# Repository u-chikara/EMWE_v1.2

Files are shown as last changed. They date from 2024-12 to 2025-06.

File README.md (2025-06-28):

# EMWE_v1.2

2024年度NHK高専ロボコンに出場したロボット「ひまり」と「ほしかご」に搭載していたメインマイコンボードの設計図です。

メインプロセッサ：ATSAME54N19A
統合開発環境：MPLAB

主な機能

CAN-FD 2チャンネル

SERCOM 5チャンネル（そのうち2チャンネルはコントローラと液晶用）

一応９軸IMUも付けられる

100M Ethernet

USB OTG （Type-CとTypeAをスイッチで切り替え）

SD/MMCカードスロット　マイコンに専用の回路があるのでそれで通信する

LEDとタクトスイッチをそれぞれ３つ搭載

今後のロボコンにお役立てください。

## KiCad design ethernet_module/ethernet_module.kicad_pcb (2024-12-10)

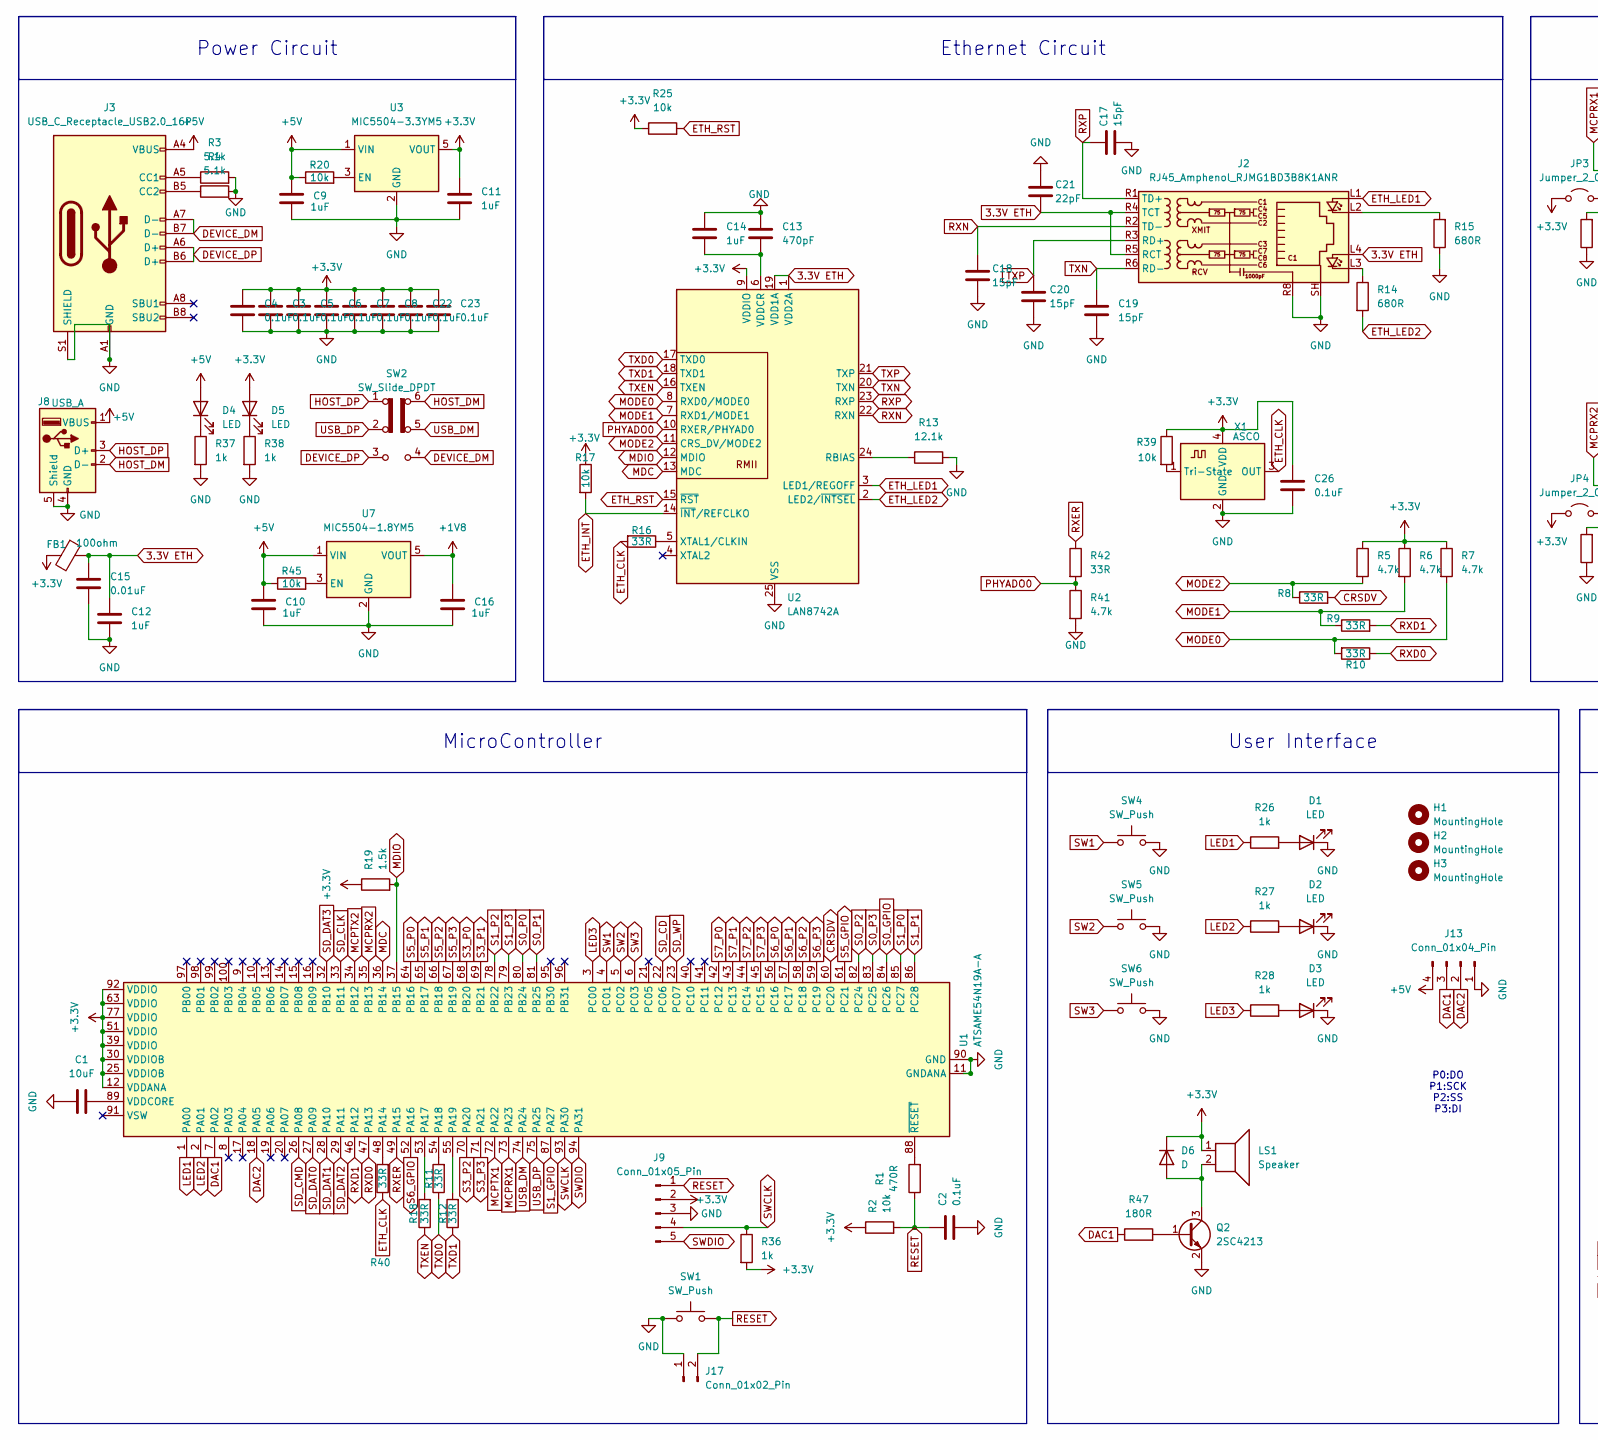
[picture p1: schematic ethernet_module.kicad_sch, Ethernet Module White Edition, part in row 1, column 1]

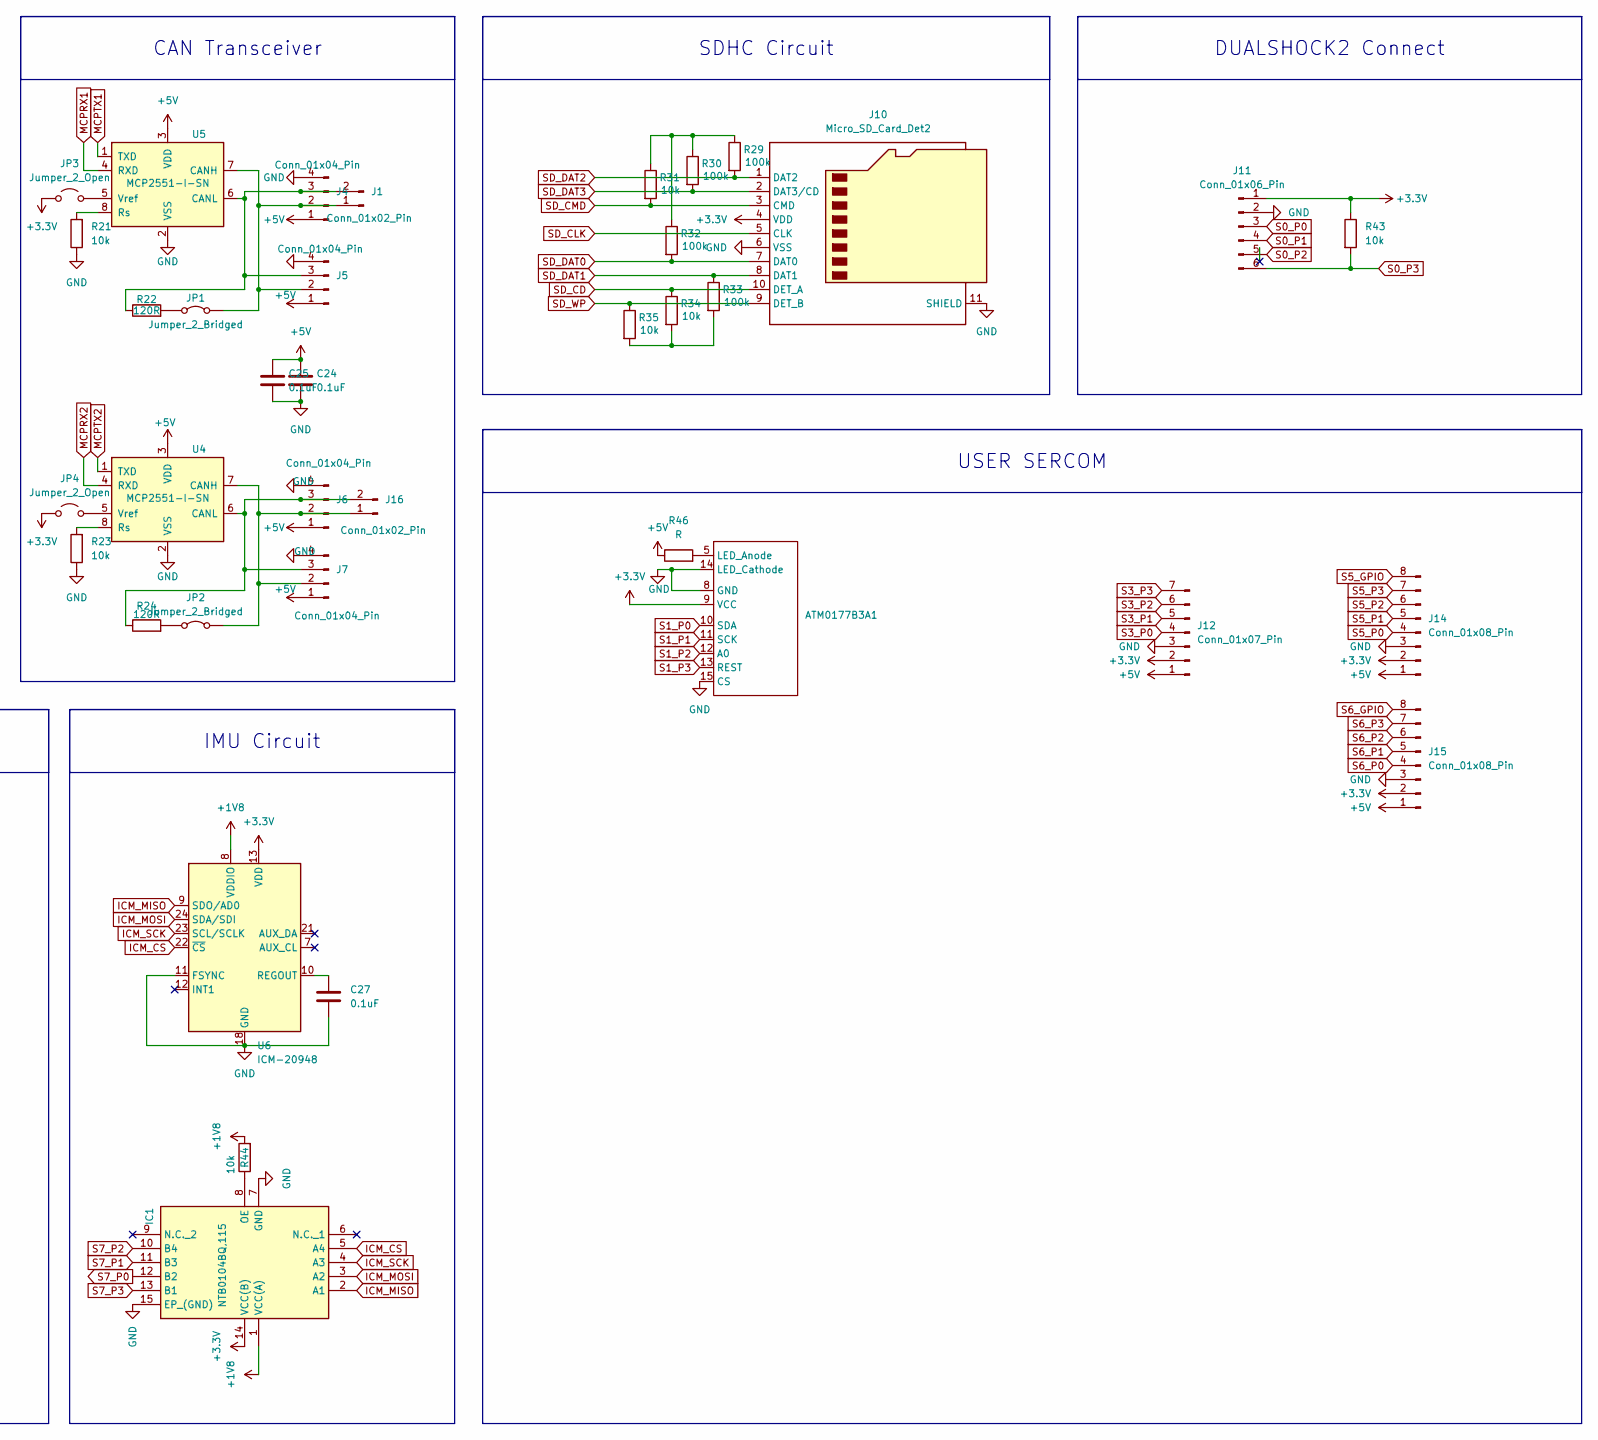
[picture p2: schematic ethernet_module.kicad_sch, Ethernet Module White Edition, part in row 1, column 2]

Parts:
ATM0177B3A1: ATM0177B3A
C1: 10uF; R_0805_2012Metric
C2, C3, C4, C5, C6, C7, C8, C22, C23, C24, C25, C26, C27: 0.1uF; R_0603_1608Metric
C9, C10, C11, C12, C14, C16: 1uF; R_0603_1608Metric
C13: 470pF; R_0603_1608Metric
C15: 0.01uF; R_0603_1608Metric
C17, C18, C19, C20: 15pF; R_0603_1608Metric
C21: 22pF; R_0603_1608Metric
D1, D2, D3, D4, D5: LED; LED_0603_1608Metric
D6: D; D_0603_1608Metric
FB1: 100ohm; R_0603_1608Metric
H1, H2, H3: MountingHole; MountingHole_2.2mm_M2_Pad
IC1: NTB0104BQ,115; NTB0104BQ115; Manufacturer_Part_Number NTB0104BQ,115; Mouser Part Number 771-NTB0104BQ115
J1, J16, J17: Conn_01x02_Pin; PinHeader_1x02_P2.54mm_Vertical
J2: RJ45_Amphenol_RJMG1BD3B8K1ANR
J3: USB_C_Receptacle_USB2.0_16P; USB_C_Receptacle_GCT_USB4105-xx-A_16P_TopMnt_Horizontal
J4, J6: Conn_01x04_Pin; JST_XA_S04B-XASK-1_1x04_P2.50mm_Horizontal
J5, J7: Conn_01x04_Pin; JST_XA_B04B-XASK-1_1x04_P2.50mm_Vertical
J8: USB_A; USB_A_CONNFLY_DS1095-WNR0
J9: Conn_01x05_Pin; JST_PH_B5B-PH-K_1x05_P2.00mm_Vertical
J10: Micro_SD_Card_Det2; microSD_HC_Hirose_DM3AT-SF-PEJM5
J11: Conn_01x06_Pin; PinHeader_1x06_P1.27mm_Vertical
J12: Conn_01x07_Pin; PinHeader_1x07_P1.27mm_Vertical
J13: Conn_01x04_Pin; PinHeader_1x04_P1.27mm_Vertical
J14, J15: Conn_01x08_Pin; PinHeader_1x08_P1.27mm_Vertical
JP1, JP2: Jumper_2_Bridged; SolderJumper-2_P1.3mm_Open_RoundedPad1.0x1.5mm
JP3, JP4: Jumper_2_Open; SolderJumper-2_P1.3mm_Open_RoundedPad1.0x1.5mm
LS1: Speaker; PUIAudio_SMT_0825_S_4_R
Q2: 2SC4213; SOT-323_SC-70
R1: 470R; R_0603_1608Metric
R2, R17, R20, R21, R23, R25, R31, R34, R35, R39, R43, R44, R45: 10k; R_0603_1608Metric
R3, R4: 5.1k; R_0603_1608Metric
R5, R6, R7, R41: 4.7k; R_0603_1608Metric
R8, R9, R10, R11, R12, R16, R18, R40, R42: 33R; R_0603_1608Metric
R13: 12.1k; R_0603_1608Metric
R14, R15: 680R; R_0603_1608Metric
R19: 1.5k; R_0603_1608Metric
R22, R24: 120R; R_0603_1608Metric
R26, R27, R28, R36, R37, R38: 1k; R_0603_1608Metric
R29, R30, R32, R33: 100k; R_0603_1608Metric
R46: R; R_0603_1608Metric
R47: 180R; R_0603_1608Metric
SW1, SW4, SW5, SW6: SW_Push; SW_Push_1P1T_NO_CK_KMR2
SW2: SW_Slide_DPDT; SW_CK_JS202011CQN_DPDT_Straight
U1: ATSAME54N19A-A; TQFP-100_14x14mm_P0.5mm
U2: LAN8742A; VQFN-24-1EP_4x4mm_P0.5mm_EP2.5x2.5mm_ThermalVias
U3: MIC5504-3.3YM5; SOT-23-5
U4, U5: MCP2551-I-SN; SOIC-8_3.9x4.9mm_P1.27mm
U6: ICM-20948; InvenSense_QFN-24_3x3mm_P0.4mm
U7: MIC5504-1.8YM5; SOT-23-5
X1: ASCO; Oscillator_SMD_Abracon_ASE-4Pin_3.2x2.5mm

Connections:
3.3V ETH: C12.1, C15.1, C21.2, FB1.1, J2.L4, J2.R4 (TCT), J2.R5 (RCT), U2.1 (VDD2A), U2.19 (VDD1A)
+1V8: C16.1, IC1.1 (VCC(A)), R44.2, U6.8 (VDDIO), U7.5 (VOUT)
+3.3V: ATM0177B3A1.9 (VCC), C3.1, C4.1, C5.1, C6.1, C7.1, C8.1, C11.1, C22.1, C23.1, C26.1, D5.2 (A), D6.1 (K), FB1.2, IC1.14 (VCC(B)), J9.2, J10.4 (VDD), J11.1, J12.2, J14.2, J15.2, JP3.1 (A), JP4.1 (A), LS1.1, R2.1, R5.1, R6.1, R7.1, R17.1, R19.1, R25.1, R36.2, R39.1, R43.1, U1.12 (VDDANA), U1.25 (VDDIOB), U1.30 (VDDIOB), U1.39 (VDDIO), U1.51 (VDDIO), U1.63 (VDDIO), U1.77 (VDDIO), U1.92 (VDDIO), U2.9 (VDDIO), U3.5 (VOUT), U6.13 (VDD), X1.4 (VDD)
+5V: C9.1, C10.1, C24.1, C25.1, D4.2 (A), J3.A4 (VBUS), J3.A9 (VBUS), J3.B4 (VBUS), J3.B9 (VBUS), J4.1, J5.1, J6.1, J7.1, J8.1 (VBUS), J12.1, J13.4, J14.1, J15.1, R20.1, R45.1, R46.1, U3.1 (VIN), U4.3 (VDD), U5.3 (VDD), U7.1 (VIN)
CRSDV: R8.2, U1.60 (PC20)
DAC1: J13.3, R47.1, U1.7 (PA02)
DAC2: J13.2, U1.18 (PA05)
DEVICE_DM: J3.A7 (D-), J3.B7 (D-), SW2.4 (A)
DEVICE_DP: J3.A6 (D+), J3.B6 (D+), SW2.3 (C)
ETH_CLK: R16.2, R40.1, X1.3 (OUT)
ETH_INT: R17.2, U2.14 (~INT/REFCLKO)
ETH_LED1: J2.L1, U2.3 (LED1/REGOFF)
ETH_LED2: R14.2, U2.2 (LED2/~INTSEL)
ETH_RST: R25.2, U2.15 (~RST)
GND: ATM0177B3A1.8 (GND), ATM0177B3A1.14 (LED_Cathode), ATM0177B3A1.15 (CS), C1.1, C2.2, C3.2, C4.2, C5.2, C6.2, C7.2, C8.2, C9.2, C10.2, C11.2, C12.2, C13.1, C14.1, C15.2, C16.2, C17.2, C18.2, C19.2, C20.2, C21.1, C22.2, C23.2, C24.2, C25.2, C26.2, C27.2, D1.1 (K), D2.1 (K), D3.1 (K), IC1.7 (GND), IC1.15 (EP_(GND)), J2.R8, J2.SH, J3.A1 (GND), J3.A12 (GND), J3.B1 (GND), J3.B12 (GND), J3.S1 (SHIELD), J4.4, J5.4, J6.4, J7.4, J8.4 (GND), J8.5 (Shield), J9.3, J10.6 (VSS), J10.11 (SHIELD), J11.2, J12.3, J13.1, J14.3, J15.3, J17.1, Q2.2 (E), R3.2, R4.2, R13.2, R15.1, R21.1, R23.1, R37.2, R38.2, R41.2, SW1.1, SW4.2, SW5.2, SW6.2, U1.11 (GNDANA), U1.24 (GND), U1.31 (GND), U1.38 (GND), U1.50 (GND), U1.62 (GND), U1.76 (GND), U1.90 (GND), U2.25 (VSS), U3.2 (GND), U4.2 (VSS), U5.2 (VSS), U6.11 (FSYNC), U6.18 (GND), U6.20 (GND), U7.2 (GND), X1.2 (GND)
HOST_DM: J8.2 (D-), SW2.6 (C)
HOST_DP: J8.3 (D+), SW2.1 (A)
ICM_CS: IC1.5 (A4), U6.22 (~CS)
ICM_MISO: IC1.2 (A1), U6.9 (SDO/AD0)
ICM_MOSI: IC1.3 (A2), U6.24 (SDA/SDI)
ICM_SCK: IC1.4 (A3), U6.23 (SCL/SCLK)
LED1: R26.1, U1.1 (PA00)
LED2: R27.1, U1.2 (PA01)
LED3: R28.1, U1.3 (PC00)
MCPRX1: U1.73 (PA23), U5.4 (RXD)
MCPRX2: U1.35 (PB13), U4.4 (RXD)
MCPTX1: U1.72 (PA22), U5.1 (TXD)
MCPTX2: U1.34 (PB12), U4.1 (TXD)
MDC: U1.36 (PB14), U2.13 (MDC)
MDIO: R19.2, U1.37 (PB15), U2.12 (MDIO)
MODE0: R7.2, R10.2, U2.8 (RXD0/MODE0)
MODE1: R6.2, R9.1, U2.7 (RXD1/MODE1)
MODE2: R5.2, R8.1, U2.11 (CRS_DV/MODE2)
unnamed: ATM0177B3A1.5 (LED_Anode), R46.2
unnamed: D1.2 (A), R26.2
unnamed: D2.2 (A), R27.2
unnamed: D3.2 (A), R28.2
unnamed: D4.1 (K), R37.1
unnamed: D5.1 (K), R38.1
unnamed: D6.2 (A), LS1.2, Q2.3 (C)
unnamed: IC1.8 (OE), R44.1
unnamed: J1.1, J4.2, J5.2, JP1.2 (B), U5.7 (CANH)
unnamed: J1.2, J4.3, J5.3, R22.1, U5.6 (CANL)
unnamed: J2.L2, R15.2
unnamed: J2.L3, R14.1
unnamed: J3.A5 (CC1), R3.1
unnamed: J3.B5 (CC2), R4.1
unnamed: J6.2, J7.2, J16.1, JP2.2 (B), U4.7 (CANH)
unnamed: J6.3, J7.3, J16.2, R24.1, U4.6 (CANL)
unnamed: JP1.1 (A), R22.2
unnamed: JP2.1 (A), R24.2
unnamed: JP3.2 (B), U5.5 (Vref)
unnamed: JP4.2 (B), U4.5 (Vref)
unnamed: Q2.1 (B), R47.2
unnamed: R29.1, R30.1, R31.1, R32.1
unnamed: R33.2, R34.2, R35.2
unnamed: R40.2, U1.48 (PA14)
unnamed: R18.2, U1.53 (PA17)
unnamed: R11.2, U1.54 (PA18)
unnamed: R12.2, U1.55 (PA19)
unnamed: C1.2, U1.89 (VDDCORE)
unnamed: R1.2, U1.88 (~RESET)
unnamed: R13.1, U2.24 (RBIAS)
unnamed: C13.2, C14.2, U2.6 (VDDCR)
unnamed: R16.1, U2.5 (XTAL1/CLKIN)
unnamed: R20.2, U3.3 (EN)
unnamed: R23.2, U4.8 (Rs)
unnamed: R21.2, U5.8 (Rs)
unnamed: C27.1, U6.10 (REGOUT)
unnamed: R45.2, U7.3 (EN)
unnamed: R39.2, X1.1 (Tri-State)
PHYADO0: R41.1, R42.2, U2.10 (RXER/PHYAD0)
RESET: C2.1, J9.1, J17.2, R1.1, R2.2, SW1.2
RXD0: R10.1, U1.47 (PA13)
RXD1: R9.2, U1.46 (PA12)
RXER: R42.1, U1.49 (PA15)
RXN: C18.1, J2.R2 (TD-), U2.22 (RXN)
RXP: C17.1, J2.R1 (TD+), U2.23 (RXP)
S0_GPIO: U1.84 (PC26)
S0_P0: J11.3, U1.80 (PB24)
S0_P1: J11.4, U1.81 (PB25)
S0_P2: J11.5, U1.82 (PC24)
S0_P3: J11.6, R43.2, U1.83 (PC25)
S1_GPIO: U1.87 (PA27)
S1_P0: ATM0177B3A1.10 (SDA), U1.85 (PC27)
S1_P1: ATM0177B3A1.11 (SCK), U1.86 (PC28)
S1_P2: ATM0177B3A1.12 (A0), U1.78 (PB22)
S1_P3: ATM0177B3A1.13 (REST), U1.79 (PB23)
S3_P0: J12.4, U1.68 (PB20)
S3_P1: J12.5, U1.69 (PB21)
S3_P2: J12.6, U1.70 (PA20)
S3_P3: J12.7, U1.71 (PA21)
S5_GPIO: J14.8, U1.61 (PC21)
S5_P0: J14.4, U1.64 (PB16)
S5_P1: J14.5, U1.65 (PB17)
S5_P2: J14.6, U1.66 (PB18)
S5_P3: J14.7, U1.67 (PB19)
S6_GPIO: J15.8, U1.52 (PA16)
S6_P0: J15.4, U1.56 (PC16)
S6_P1: J15.5, U1.57 (PC17)
S6_P2: J15.6, U1.58 (PC18)
S6_P3: J15.7, U1.59 (PC19)
S7_P0: IC1.12 (B2), U1.42 (PC12)
S7_P1: IC1.11 (B3), U1.43 (PC13)
S7_P2: IC1.10 (B4), U1.44 (PC14)
S7_P3: IC1.13 (B1), U1.45 (PC15)
SD_CD: J10.10 (DET_A), R34.1, U1.22 (PC06)
SD_CLK: J10.5 (CLK), U1.33 (PB11)
SD_CMD: J10.3 (CMD), R31.2, U1.26 (PA08)
SD_DAT0: J10.7 (DAT0), R32.2, U1.27 (PA09)
SD_DAT1: J10.8 (DAT1), R33.1, U1.28 (PA10)
SD_DAT2: J10.1 (DAT2), R29.2, U1.29 (PA11)
SD_DAT3: J10.2 (DAT3/CD), R30.2, U1.32 (PB10)
SD_WP: J10.9 (DET_B), R35.1, U1.23 (PC07)
SW1: SW4.1, U1.4 (PC01)
SW2: SW5.1, U1.5 (PC02)
SW3: SW6.1, U1.6 (PC03)
SWCLK: J9.4, R36.1, U1.93 (PA30)
SWDIO: J9.5, U1.94 (PA31)
TXD0: R11.1, U2.17 (TXD0)
TXD1: R12.1, U2.18 (TXD1)
TXEN: R18.1, U2.16 (TXEN)
TXN: C19.1, J2.R6 (RD-), U2.20 (TXN)
TXP: C20.1, J2.R3 (RD+), U2.21 (TXP)
USB_DM: SW2.5 (B), U1.74 (PA24)
USB_DP: SW2.2 (B), U1.75 (PA25)

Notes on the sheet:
MicroController
User Interface
DUALSHOCK2 Connect
Ethernet Circuit
USER SERCOM
CAN Transceiver
IMU Circuit
Power Circuit
SDHC Circuit
P0:DO P1:SCK P2:SS P3:DI

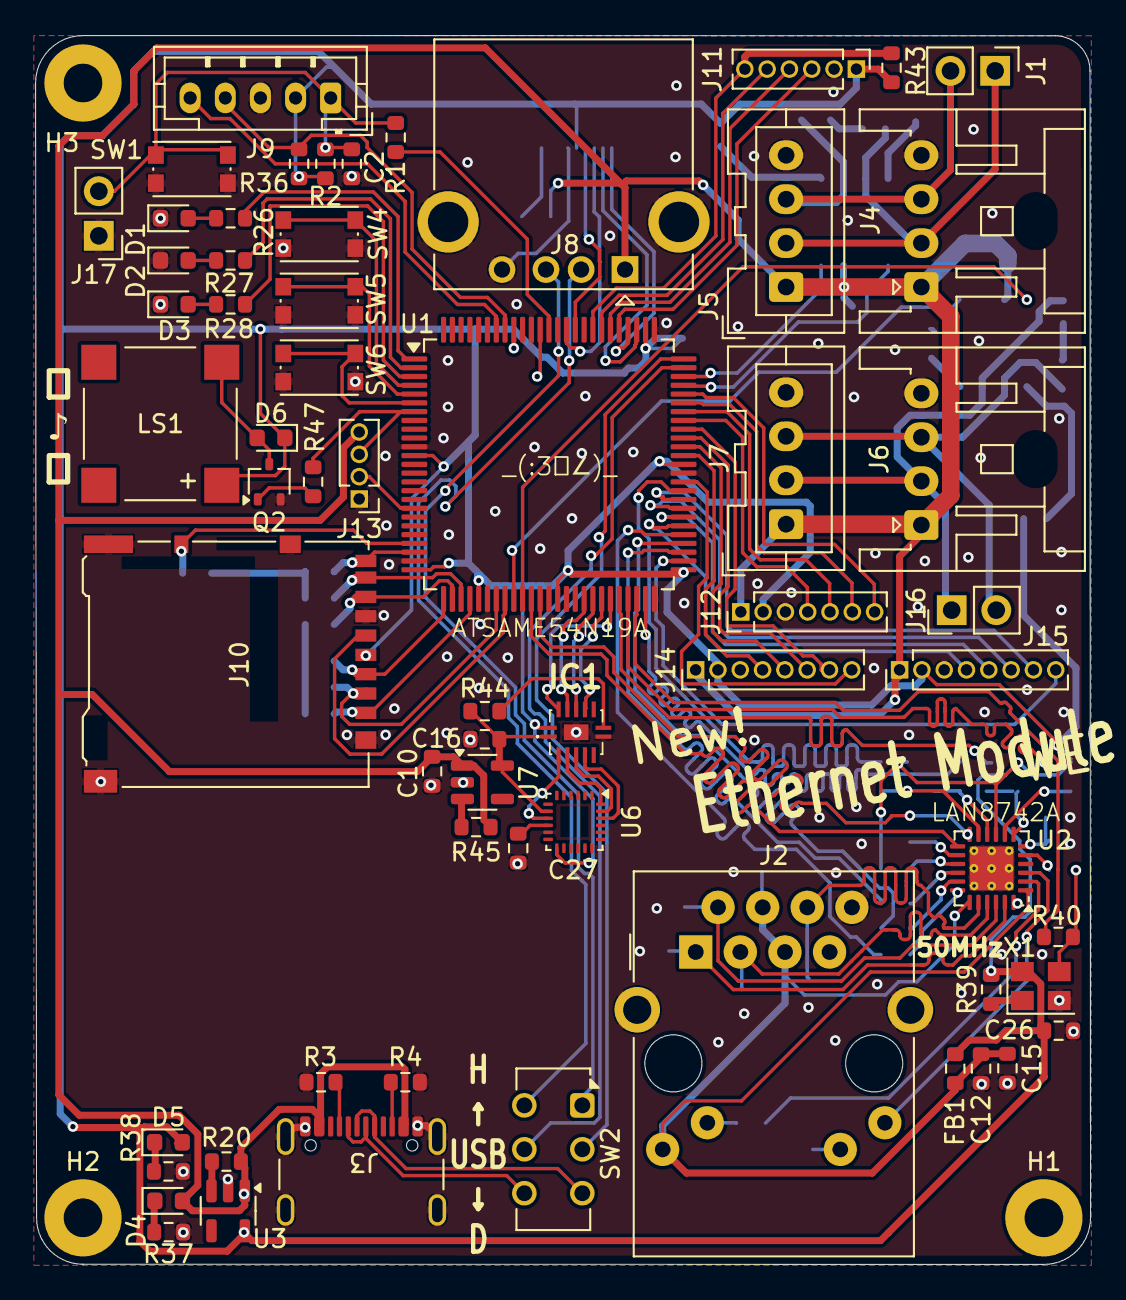
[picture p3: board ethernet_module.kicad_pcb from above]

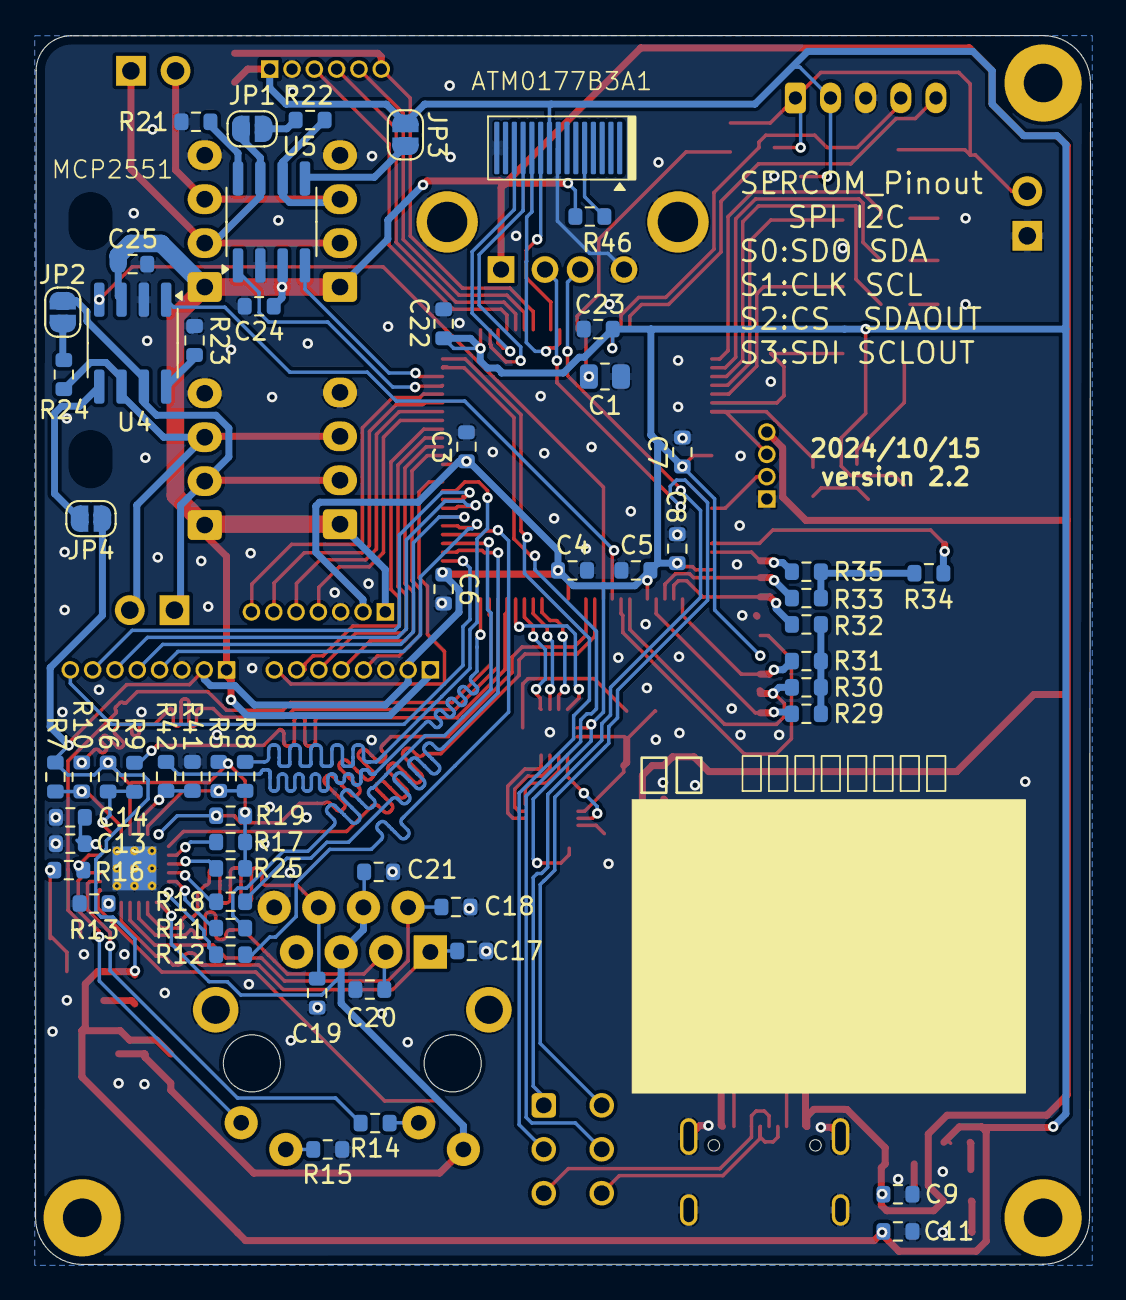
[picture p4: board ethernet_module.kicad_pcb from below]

Board: 2 copper layers, 60.1 x 70.0 mm, 122 parts (57 on the bottom side), 124 nets.
